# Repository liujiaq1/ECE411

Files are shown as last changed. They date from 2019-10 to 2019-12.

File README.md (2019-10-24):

# ECE411

## Team Members:
- Wenhao Cheng [cwenhao@pdx.edu](cwenhao@pdx.edu)
- Blaine R. Jemmett [brj@pdx.edu](brj@pdx.edu)
- Xuening Jia [xuening@pdx.edu](xuening@pdx.edu)
- Jiaqi Liu [liujiaq@pdx.edu](liujiaq@pdx.edu)

## Resources: 
- [ECE 411 Syllabus](http://web.cecs.pdx.edu/~faustm/ece411/syllabus.pdf)
- [ Practicum Project Information and Requirements](http://web.cecs.pdx.edu/~faustm/ece411/homework/PracticumProjectDescription.pdf)

## Meeting Minutes
- [10/17/2019](https://github.com/liujiaq1/ECE411-Team9/blob/master/Meetings/10-17-2019/README.md)

## Parts 
- [Parts List](https://github.com/liujiaq1/ECE411-Team9/blob/master/Parts%20List.xlsx)
- [Datasheets](https://github.com/liujiaq1/ECE411-Team9/blob/master/Datasheets/README.md)

## Homework Documents
- [HW2](https://github.com/liujiaq1/ECE411-Team9/blob/master/HWDocument/ECE411%20HW2.docx)
- [PDS](https://github.com/liujiaq1/ECE411-Team9/blob/master/HWDocument/PDS.pdf)

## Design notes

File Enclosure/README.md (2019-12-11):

# Enclosure

<center>
<table>
  <tr>
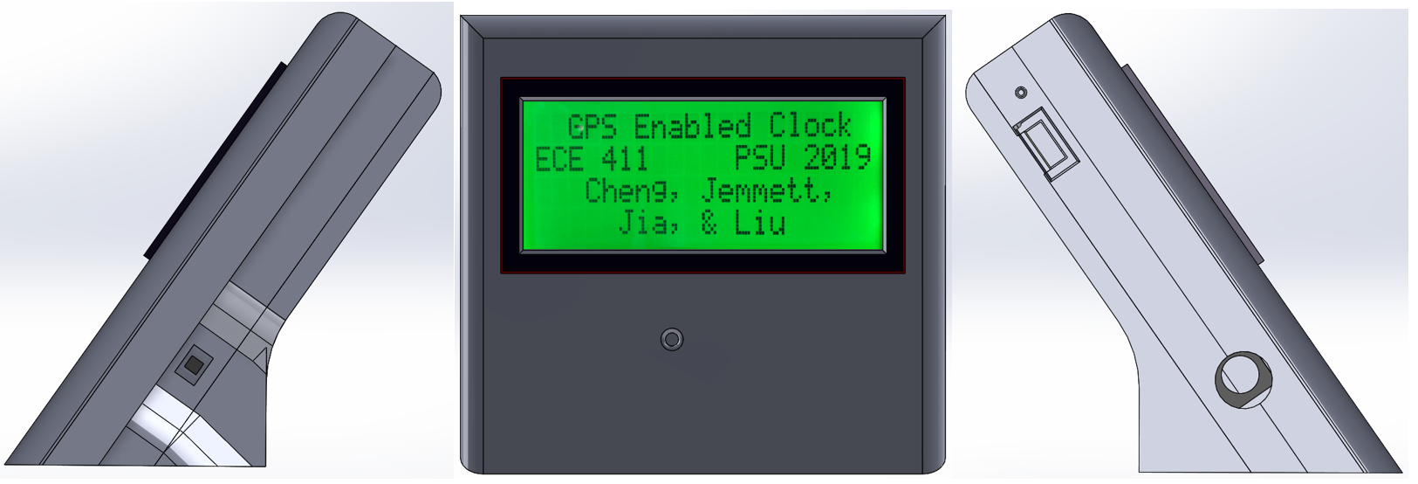
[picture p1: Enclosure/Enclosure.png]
Enclosure
    
  </tr>
  <tr>
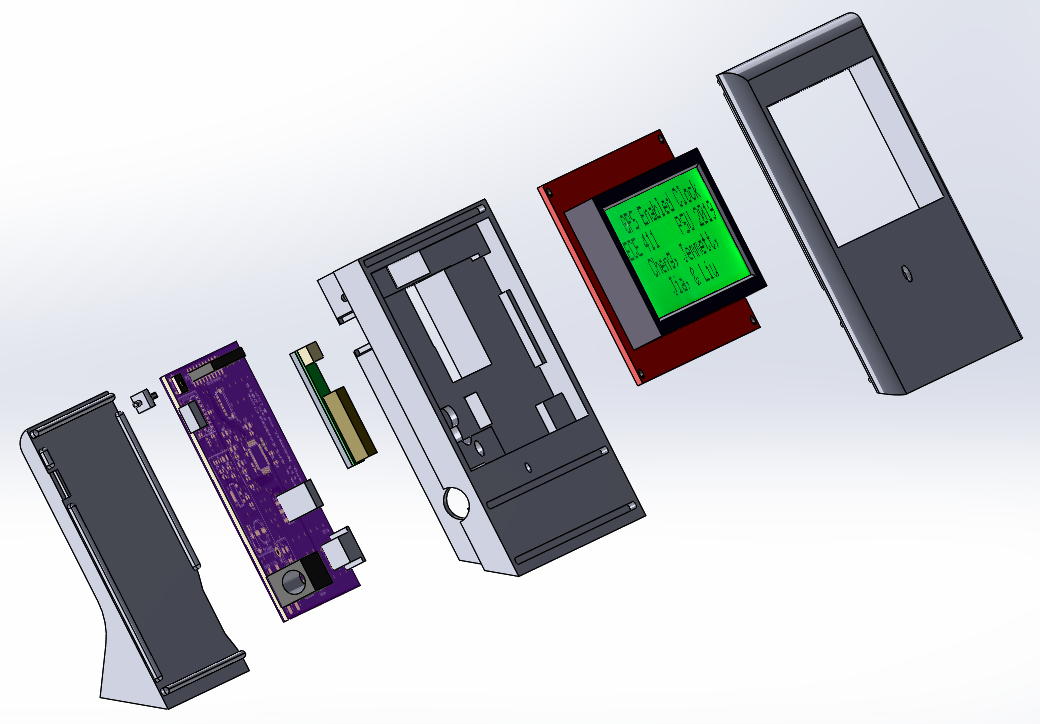
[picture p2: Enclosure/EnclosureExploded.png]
Exploder Enclosure
    
  </tr>
</table>
</center>

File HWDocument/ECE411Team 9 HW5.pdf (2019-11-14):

## ECE 411 Industry Design Processes: Assignment #5

## Due on Thursday, November 14, 2019

## Team: T09

## W. Cheng, Blaine R. Jemmett, X. Jia, J. Liu

Draw a high-level block diagram of your practicum project showing all inputs and

outputs.

# GPS enabled clock: Level 0

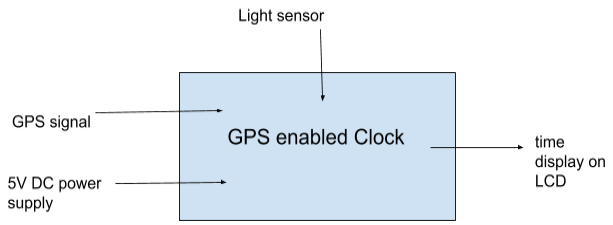
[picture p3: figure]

Module | GPS enabled clock
Inputs | Light sensor, GPS receiver, DC power supply
Outputs | 20x4 RGB LCD
Functionality | Uses a GPS receiver that receives location information and sends it to the Adruino. Then, Adruino will set the time automatically on LCD.

# GPS enabled clock: Level 1

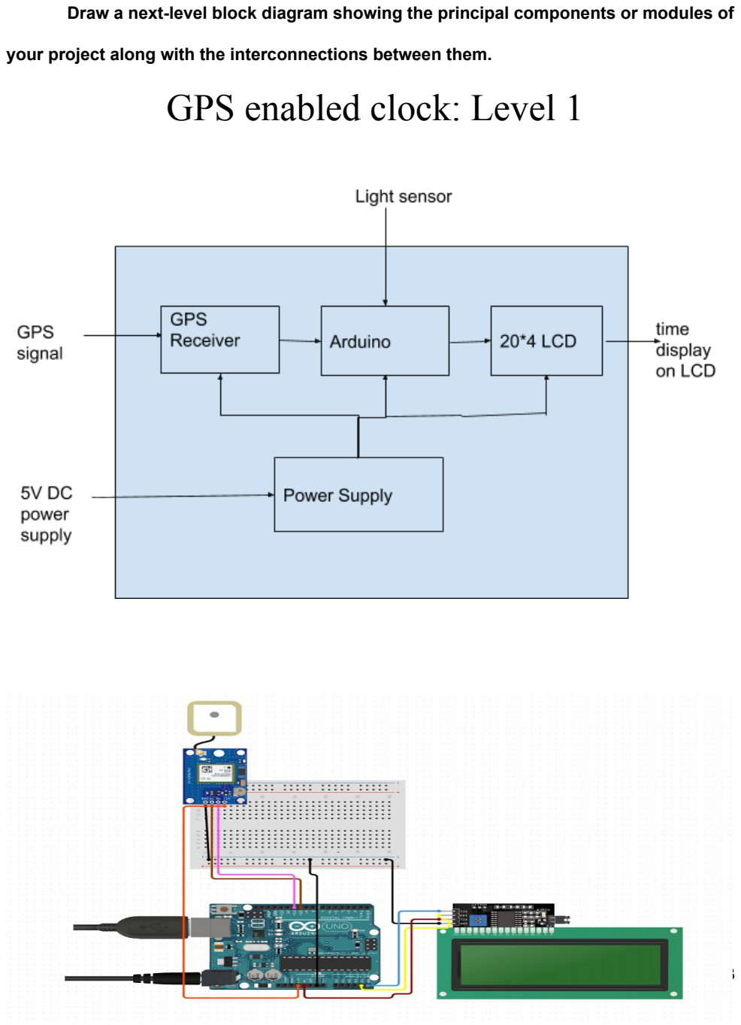
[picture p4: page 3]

Draw a next-level block diagram showing the principal components or modules of

your project along with the interconnections between them.

Draw a next-level block diagram showing the principal components or modules of your

project along with the interconnections between them.

# GPS Receiver: Level 1

For each component or module in the next-level block diagram, create a top-level block

diagram of that component or module that describes its functionality, inputs, and

outputs.

Module | GPS Receiver
Inputs | GPS signal, 3.3V from Power Supply
Outputs | GPS data sent to Arduino
Functionality | GPS Receiver can get the user position, velocity and precise time, by processing the signal broadcast by the GPS satellites.

# Arduino: Level 1

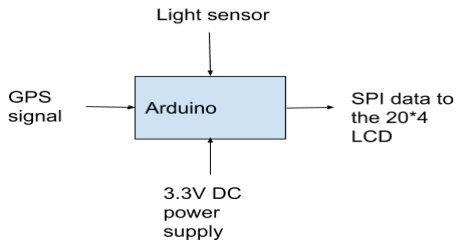
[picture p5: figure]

Module | Arduino
Inputs | GPS data from GPS receiver, 3.3V from Power Supply, Light sensor
Outputs | SPI data to the 20*4 LCD
Functionality | Arduino can receive and analyze GPS information. Finally, the result is shown on LCD. Brightness to LCD should be controlled by the amount of light received at the light sensor.

# 20*4 LCD: Level 1

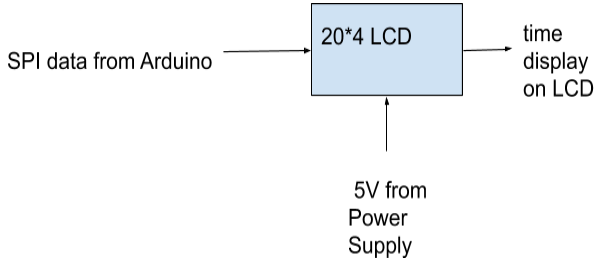
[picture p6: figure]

Module | 20*4 LCD
Inputs | SPI data from Arduino, 5V from Power Supply
Outputs | Visual information on the display screen
Functionality | Displaying text (time, date, etc) sent by Arduino.

# Power Supply: Level 1

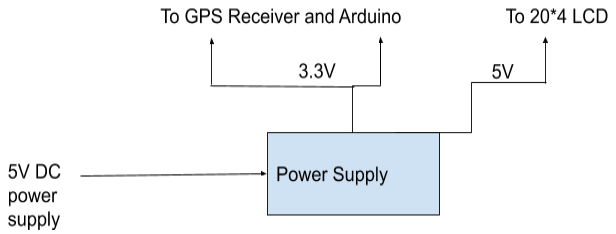
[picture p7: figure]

Module | Power Supply
Inputs | 5V DC power supply
Outputs | 5V/3.3V DC power supply
Functionality | It provides the power the whole device using a 120V AC power supply to 5V DC power supply or USB.

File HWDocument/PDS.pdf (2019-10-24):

## ECE 411 Industry Design Processes: Assignment #2

## Due on Thursday, October 24, 2019

## Team: T09

## W. Cheng, Blaine R. Jemmett, X. Jia, J. Liu

## Project Design Specification (PDS)

## for

## GPS enabled clock

## Version 1.0

## October 24, 2019

## Table of Contents

Introduction

Purpose of the Product Design Specification Document

Project Overview

System Architecture

Requirements

Functional Requirements

Performance Requirements

Economic and Marketing Requirements

Power Requirements

Health and Safety

Maintainability

Operational Environment

Usability

REFERENCES

Introduction:

A GPS clock having high precision positioning timing prevents people from having to

manually adjust to local time when they go to different places. The GPS clock is not affected by

various electromagnetic interferences, and the time is accurate and is not limited by geography.

Although such products are already on the market, the expensive price cannot meet the

budgetary requirements of ordinary families. The purpose of the project is to create this clock

having more accurate time at a lower price so that more people can afford it.

Purpose of the Product Design Specification Document:

The purpose of the product design specification is to confirm that the subsequent design and

development of the product can meet the needs of the users. The project must meet all the

requirements that “Must” be completed in the specification document. “Should” and “May” are

additional but not necessary.

Project Overview

This project solves the problem of the prohibitive cost of traditional GPS clocks. The

GPS clock has a GPS receiver - GP-735 (56 channels) that receives GPS satellite signals. The

receiver is very small and convenient, and it can turn on/off the power through the GPIO control

pin. This can achieve the purpose of saving power loss when the GPS function is not used.

Therefore, the project achieves a small size, low cost, energy-saving, etc.

System Architecture

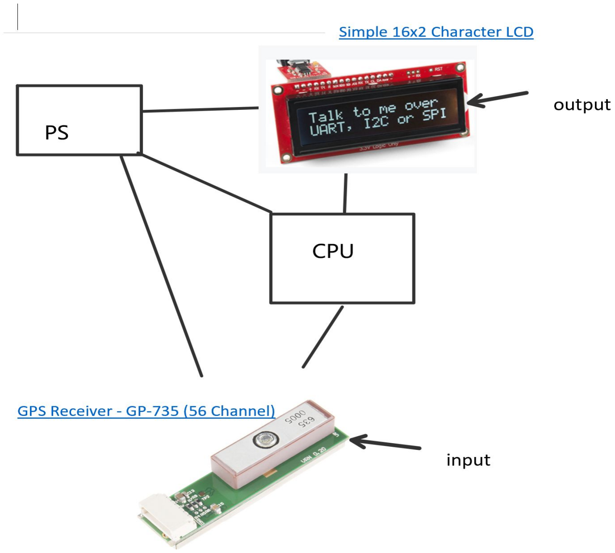
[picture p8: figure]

User Characteristic

The following sections list the main user types to better describe the expected target

market.

- Students

The people who live and study in different places or different time zone is more likely to

buy this product. They can know the time even they go back home or go to school without

setting a clock. It is very convenient for these people to know the time.

- Commuters and Travelers

People who like to fly or bus are always very time-conscious, and they are always

worried about missing flights or trains. The GPS clock accurately provides them with the correct

time for appropriate arrival times.

Assumptions

- Users are familiar with the ECE 411 practicum design guidelines.
- The system works in different regions.
- The system is at the temperature at which it can work.

Constraints

- Must be completed within a limited time (8 to 10 weeks).
- Use a two or more layer PCB.
- Have one or more sensors (inputs).
- Have one or more actuators (outputs).
- Have one or more processing modules which control actuators based on sensors.
- Use 25% or more surface mount components that can be hand or reflow soldered.

Requirements:

### 1. Functional Requirements:

Req# | Requirement | Priority | Station
1.1 | Have one or more inputs or sensors | Must | GPS module
1.2 | receive GPS signal | Must | GPS module
1.3 | Communicate with an alphanumeric display by a simple SPI interface | Must | LCD/GPS module
1.4 | Hot and cold resistant | Should | LCD/GPS module
1.5 | Detect ambient light levels and adjust LCD accordingly | Should | LCD Module
1.6 | Alarm setting | Should | CPU
1.7 | Automatically adjust for DST | Should | CPU
Table 1: Functional Requirements

### 2. Performance Requirements:

Req# | Requirement | Priority | Station
2.1 | GPS module update frequency range is 5Hz -10Hz | Must | GPS module
2.2 | These tiny GPS units can use a lot of power around 30mA at 3.3V On average | Must | GPS module

Table 2: Performance Requirements

### 3. Economic and Marketing Requirements:

Req# | Requirement | Priority | Station
3.1 | Should not use non-standard components | Should | GPS module
3.2 | Buying 25 or more will save $3.76/each | Should | LCD/GPS module
3.3 | The whole product can be sold as $60 | Should | LCD/GPS module

Table 3: Economic and Marketing Requirements

### 4. Power Requirements:

Req# | Requirement | Priority | Station
4.1 | A 5V (https://www.sparkfun.com/products/12889) Wall Adapter Power Supply provides all the power for the displays and to power the Arduino | Must | LCD/GPS module
4.2 | Peak current shall not exceed 2000mA | Must | LCD/GPS module
4.3 | The GPS module to be powered down when not in use | Must | GPS module

Table 4: Power Requirements

### 5. Health and Safety:

Req# | Requirement | Priority | Station
5.1 | Make sure the product will not injure people. | Must | LCD/GPS module

Table 5: Health and Safety

### 6. Maintainability:

Req# | Requirement | Priority
6.1 | Record the progress of the project every week | Must
6.2 | Progress reports may be submitted by email | May
6.3 | Record experimental data and results via Github | May

Table 6: Maintainability

### 7. Operational Environment:

Req# | Requirement | Priority | Station
7.1 | Can work in hot and cold environments | Should | LCD/GPS module

Table 7: Operational Environment

### 8. Usability:

Req# | Requirement | Priority | Station
8.1 | Users are able to use the system without training | Must | LCD/GPS module

Table 8: Usability

### 9. Manufacturability:

Req# | Requirement | Priority | Station
9.1 | Must be possible to assemble by hand | Must | LCD/GPS module
9.2 | Use 25% or more surface mount components that can be hand or reflow soldered | Must | LCD/GPS module

Table 9: Manufacturability

REFERENCES

https://en.wikipedia.org/wiki/Product_design_specification

https://learn.sparkfun.com/tutorials/gps-basics

https://en.wikipedia.org/wiki/Global_Positioning_System

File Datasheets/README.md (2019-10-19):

# Datasheets

<table>
  <tr>
    <th>Part</th> <th>Datasheet</th>
  </tr>
    <td><a href="https://www.sparkfun.com/products/13448">ATMEGA328P-AU</a></td> <td><a href="https://github.com/liujiaq1/ECE411-Team9/blob/master/Datasheets/ATMega328.pdf">PDF Datasheet</a></td>
  <tr>
    <td><a href="https://www.sparkfun.com/products/14074">SparkFun 20x4 SerLCD - Black on RGB 3.3V</a></td> <td><a href="https://github.com/sparkfun/OpenLCD">Datasheet Link</a></td>
  </tr>
  <tr>
    <td><a href="https://www.sparkfun.com/products/13670">GPS Receiver - GP-735 (56 Channel)</a></td> <td><a href="https://github.com/liujiaq1/ECE411-Team9/blob/master/Datasheets/GP-735T-150203.pdf">PDF Datasheet</a></td>
  </tr>
  <tr>
    <td><a href="https://www.sparkfun.com/products/12566">ALS-PT19 Light Sensor</a></td> <td><a href="https://github.com/liujiaq1/ECE411-Team9/blob/master/Datasheets/ALS-PT19-315C-L177-TR_datasheet.pdf">PDF Datasheet</a></td>
  </tr>
  <tr>
    <td></td> <td></td>
  </tr>   
</table>

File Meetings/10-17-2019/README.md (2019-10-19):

# Attendees
<pre>
Blaine
Jackie
Wenhao
Xuening
</pre>

# Homework
<pre>
Sorted out the differences between HW2 for Lecture vs Practicum
</pre>

# Project
<pre>
Discussed each persons background, skills, and classes
Agreed on GPS clock
Talked about and agreed on using GPS Receiver - GP-735 (56 Channel)
</pre

<table>
  <tr>
    <th><a href="https://www.sparkfun.com/products/13670" title="GPS Receiver - GP-735 (56 Channel)">GPS Receiver - GP-735 (56 Channel)</a></th>
  </tr>
</table>

<pre>
Agreed on highlevel block diagram 
</pre>

<center>
<table>
  <tr>
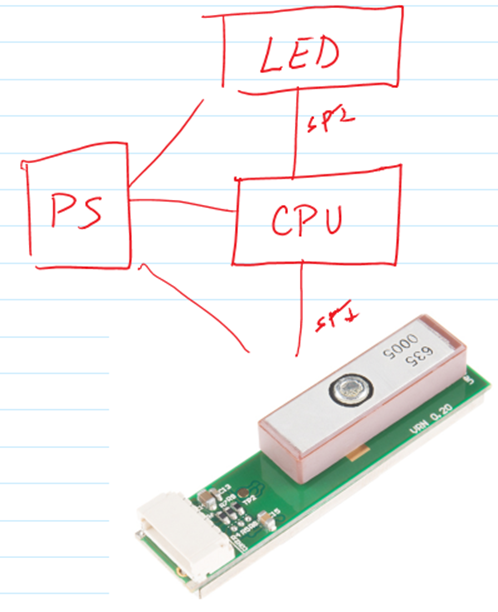
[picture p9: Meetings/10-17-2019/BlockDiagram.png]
Block Diagram
    
  </tr>
</table>
</center>

<pre>
Discussed pros and cons about simple character LCDs versus graphic LCDs. 
Compared simple 16x2 Character LCD to 128x32 graphics LCD. 
Decided to send email to ask for advice on required complexity of the project. 
</pre>

<table>
  <tr>
    <th><a href="https://www.sparkfun.com/products/14073/" title="Simple 16x2 Character LCD">Simple 16x2 Character LCD</a></th> 
    <th><a href="https://www.digikey.com/product-detail/en/newhaven-display-intl/NHD-C12832A1Z-NSW-BBW-3V3/NHD-C12832A1Z-NSW-BBW-3V3-ND/2059235/" title="128x32 Graphics LCD">128x32 Graphics LCD</a></th>
  </tr>
  <tr>
    <td>
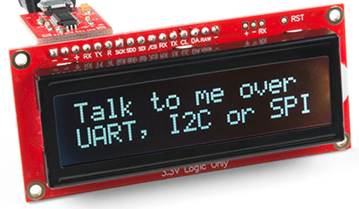
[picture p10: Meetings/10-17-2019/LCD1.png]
Simple 16x2 Character LCD
      
    </td>
    <td>
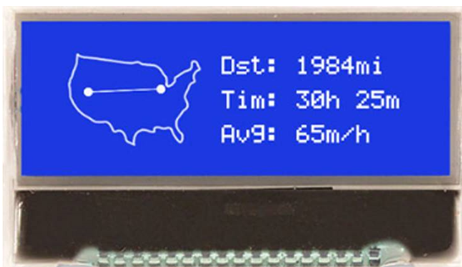
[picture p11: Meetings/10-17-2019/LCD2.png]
128x32 Graphics LCD
      
    </td>
  </tr>
</table>

<pre>
Decided to use Google Docs for collaboration on PSD
</pre>

# ARs

### Blaine: email Eric and Andrew about which LCD type would be accepable for the project 
- [x] Completed: 10\17\2019
>> [Andrew's Response. email 10/17/2019] I'm not sure what you mean by "acceptable". Both LCDs are perfectly acceptable as "actuators" in the practicum project.
**The first LCD is simple to use character-based LCD, straight forward to use, and would make an excellent choice for a simple practicum project.**
The second LCD is a widely used graphical LCD that requires a C graphics library and, in my opinion, a 32 bit microcontroller with plenty of flash and RAM. If you'd like to go down that route, that's perfectly acceptable, although of course *I wouldn't suggest you do that.*
Hope that helps.
>>
> Will use [Simple 16x2 Character LCD](https://www.sparkfun.com/products/14073/)
>

### Blaine:  Post initial parts list
- [x] Completed: 10\18\2019
>

### Jackie:  Markup practicum HW2, Post to Git, and email Andrew and Eric as soon as possible
- [ ] Completed: xx\xx\xxxx
> Insert info or delete
>

### Jackie:  Create PDS document in Google Docs
- [ ] Completed: xx\xx\xxxx
> Insert info or delete
>

### All:  Work on PDS in Google Docs
- [ ] Completed: xx\xx\xxxx
> Insert info or delete
>

### Jackie:  Post compledted PDS to GIT prior to due date
- [ ] Completed: xx\xx\xxxx
> Insert info or delete
>

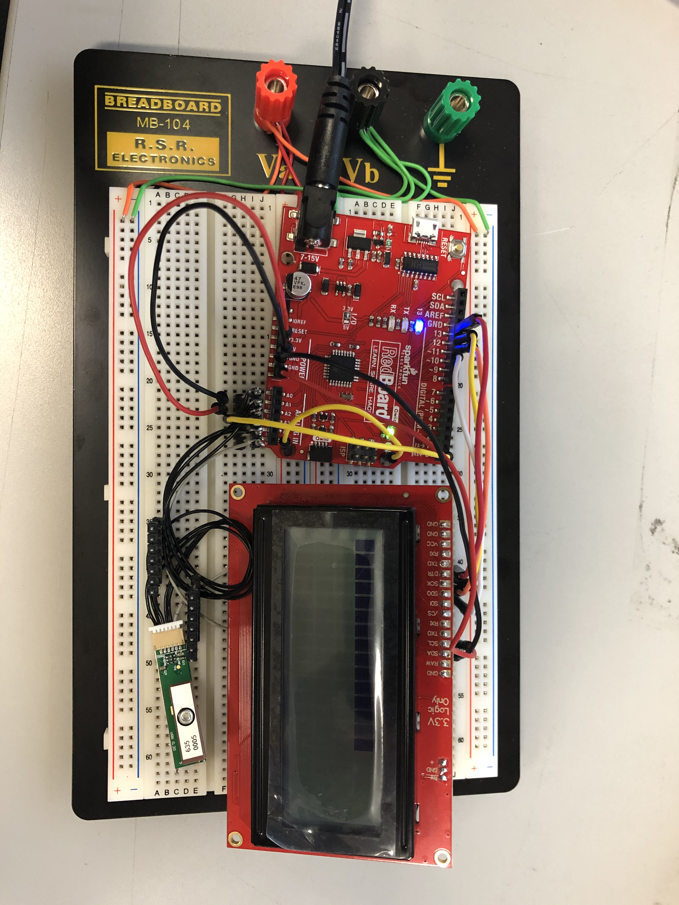
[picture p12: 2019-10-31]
HWDocument/HW4 Picture.jpg

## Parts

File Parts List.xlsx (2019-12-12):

Status | Part |  | Link | Quantity |  | Price |  |  | Vmin | Vmax | Through Hole |  | SMD |  |  | Bought
 |  | Source |  | Per Board | Total | Per Part | Per Board | Total |  |  |  | QTY |  | QTY |  | Cheng | Jemmett | Jia | Liu
 | PCB | Osh Park |  | 1 | 4 | $8.51 | $8.51 | $34.04
In House | GPS Module | Sparkfun | https://www.sparkfun.com/products/13670 | 1 | 4 | $45.95 | $45.95 | $183.80 | 3.1 | 5.5 |  |  |  |  |  |  | 1
In House | Solder Stencil kit | Osh Stencil |  |  |  |  | $15.53 | $62.11
In House | GPS PCB Connector | Sparkfun | https://www.sparkfun.com/products/10210 | 1 | 4 | $0.95 | $0.95 | $3.80 |  |  |  |  |  |  |  |  | 2
In House | 20x4 RGB LCD | Sparkfun | https://www.sparkfun.com/products/14074 | 1 | 4 | $24.95 | $24.95 | $99.80 | 3.3 | 9 |  |  | X | 1 |  |  | 2
In House | Light sensor | Sparkfun | https://www.sparkfun.com/products/12566 | 1 | 4 | $0.95 | $0.95 | $3.80 | -0.5 | 6 |  |  | X | 1 |  |  | 3
In House | ATMEGA328P-AU | Sparkfun | https://www.sparkfun.com/products/13448 | 1 | 4 | $4.25 | $4.25 | $17.00 | 1.8 | 5 |  |  | X | 1 |  |  | 2
In House | Cap: 0.1UF-0603-25V-(+80/-20%) | Digi-Key | https://www.digikey.com/product-detail/en/kemet/C0603C104Z3VACTU/399-1100-1-ND/411375 | 10 | 40 | $0.10 | $1.00 | $4.00 |  |  |  |  | X | 10 |  |  | 20
In House | Cap: 1.0UF-16V-10%(0603) | Digi-Key | https://www.digikey.com/product-detail/en/knowles-novacap/0603BB105K160YT/1763-1175-1-ND/7304294 | 1 | 4 | $1.61 | $1.61 | $6.44 |  |  |  |  | X | 1 |  |  | 10
In House | Res: 10KOHM-0603-1/10W-1% | Digi-Key | https://www.digikey.com/product-detail/en/yageo/RC0603FR-0710KL/311-10.0KHRCT-ND/729827 | 3 | 12 | $0.10 | $0.30 | $1.20 |  |  |  |  | X | 3 |  |  | 10
In House | Cap: 10NF/10000PF-50V-10%(0603) | Digi-Key | https://www.digikey.com/products/en/capacitors/ceramic-capacitors/60?k=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 | 1 | 4 | $0.62 | $0.62 | $2.48 |  |  |  |  | X | 1 |  |  | 10
In House | Cap: 10UF-POLAR-EIA3216-16V-10%(TANT) | Digi-Key | https://www.digikey.com/product-detail/en/avx-corporation/F931C106KAA/478-8235-1-ND/4005599 | 3 | 12 | $0.46 | $1.38 | $5.52 |  |  |  |  | X | 3 |  |  | 10
In House | 1571984-1 | Digi-Key | https://www.digikey.com/products/en?keywords=TE%201571984-1 | 1 | 4 | $6.19 | $6.19 | $24.76 |  |  | X | 1 |  |  |  |  | 1
In House | RESONATOR-16MHZSMD_3.2X1.3 | Digi-Key | https://www.digikey.com/product-detail/en/murata-electronics/CSTNE16M0V53C000R0/490-17949-1-ND/8747757 | 1 | 4 | $0.36 | $0.36 | $1.44 |  |  |  |  | X | 1 |  |  | 5
In House | DIODE-SCHOTTKY-SS14 | Digi-Key | https://www.digikey.com/product-detail/en/on-semiconductor/SS14/SS14CT-ND/965729 | 1 | 4 | $0.39 | $0.39 | $1.56 |  |  |  |  | X | 1 |  |  | 3
In House | MOSFET-PCH-ZXMP6A13F | Digi-Key | https://www.digikey.com/product-detail/en/diodes-incorporated/ZXMP6A13FTA/ZXMP6A13FCT-ND/560665 | 1 | 4 | $0.55 | $0.55 | $2.20 |  |  |  |  | X | 1 |  |  | 3
In House | Res: 1MOHM-0603-1/4W-5% | Digi-Key | https://www.digikey.com/product-detail/en/vishay-dale/CRCW06031M00JNEAHP/541-1.0MSACT-ND/2222829 | 1 | 4 | $0.16 | $0.16 | $0.64 |  |  |  |  | X | 1 |  |  | 10
In House | Res: 1KOHM-0603-1/10W-1% | Digi-Key | https://www.digikey.com/product-detail/en/yageo/RC0603FR-071KL/311-1.00KHRCT-ND/729790 | 1 | 4 | $0.10 | $0.10 | $0.40 |  |  |  |  | X | 1 |  |  | 10
In House | Res: 240OHM-0603-1/10W-1% | Digi-Key | https://www.digikey.com/product-detail/en/stackpole-electronics-inc/RMCF0603FT240R/RMCF0603FT240RCT-ND/4376679 | 1 | 4 | $0.10 | $0.10 | $0.40 |  |  |  |  | X | 1 |  |  | 10
In House | 4.7KOHM-0603-1/10W-1% | Digi-Key | https://www.digikey.com/product-detail/en/yageo/RC0603FR-074K7L/311-4.70KHRCT-ND/730159 | 3 | 12 | $0.10 | $0.30 | $1.20 |  |  |  |  | X | 3 |  |  | 10
In House | Cap: 47UF-POLAR-PANASONIC_D-35V-20% | Digi-Key | https://www.digikey.com/product-detail/en/panasonic-electronic-components/EEE-1VA470WP/PCE3961CT-ND/766337 | 1 | 4 | $0.41 | $0.41 | $1.64 |  |  |  |  | X | 1 |  |  | 2
In House | Res: 715OHM-0603-1/10W-1% | Digi-Key | https://www.digikey.com/product-detail/en/yageo/RC0603FR-07715RL/311-715HRCT-ND/730318 | 1 | 4 | $0.10 | $0.10 | $0.40 |  |  |  |  | X | 1 |  |  | 10
In House | USB_MICRO-B_HALF_PTH_MILL | Digi-Key | https://www.digikey.com/product-detail/en/amphenol-icc-fci/10103594-0001LF/609-4050-1-ND/2350357 | 1 | 4 | $0.79 | $0.79 | $3.16 |  |  |  |  | X | 1 |  |  | 1
In House | V_REG_AP2112K-3.3V | Digi-Key | https://www.digikey.com/product-detail/en/diodes-incorporated/AP2112K-3.3TRG1/AP2112K-3.3TRG1DICT-ND/4505257 | 1 | 4 | $0.47 | $0.47 | $1.88 |  |  |  |  | X | 1 |  |  | 3
In House | LED-BLUE_HIDDENSILK | Digi-Key | https://www.digikey.com/product-detail/en/lite-on-inc/LTST-C150TBKT/160-1643-1-ND/573584 | 1 | 4 | $0.54 | $0.54 | $2.16 |  |  |  |  | X | 1 |  |  | 2
In House | LED-GREEN_HIDDENSILK | Digi-Key | https://www.digikey.com/product-detail/en/lite-on-inc/LTST-C150KGKT/160-1404-1-ND/386759 | 1 | 4 | $0.45 | $0.45 | $1.80 |  |  |  |  | X | 1 |  |  | 2
In House | LED-GREEN_HIDDENSILK | Digi-Key | https://www.digikey.com/product-detail/en/lite-on-inc/LTST-C150KGKT/160-1404-1-ND/386759 | 1 | 4 | $0.37 | $0.37 | $1.48 |  |  |  |  | X | 1 |  |  | 2
In House | AVR_SPI_PROG_3X2SMD | Digi-Key | https://www.digikey.com/product-detail/en/molex/0877590614/WM18713-ND/769538 | 1 | 4 | $0.37 | $0.37 | $1.48 |  |  |  |  | X | 1 |  |  | 1
In House | V_REG_LM1117ALT1 | Digi-Key | https://www.digikey.com/product-detail/en/texas-instruments/LM1117MPX-5.0-NOPB/LM1117MPX-5.0-NOPBCT-ND/660149 | 1 | 4 | $0.99 | $0.99 | $3.96 |  |  |  |  | X | 1 |  |  | 2
In House | PPTC_6V500MA | Digi-Key | https://www.digikey.com/product-detail/en/littelfuse-inc/0402L020SLKR/F5757CT-ND/3593804 | 1 | 4 | $1.10 | $1.10 | $4.40 |  |  |  |  | X | 1 |  |  | 2
In House | TP-063 | Digi-Key | https://www.digikey.com/product-detail/en/keystone-electronics/5011/36-5011-ND/255333 | 1 | 4 | $0.04 | $0.04 | $0.14 |  |  | X | 1 |  |  |  |  | 1
In House | LED-YELLOW_HIDDENSILK | Digi-Key | https://www.digikey.com/product-detail/en/lite-on-inc/LTST-C150KSKT/160-1406-1-ND/386762 | 1 | 4 | $1.50 | $1.50 | $6.00 |  |  |  |  | X | 1 |  |  | 2
In House | POWER_JACKSUPER_BOMB_DIGITY | Sparkfun | https://www.sparkfun.com/products/12748 | 1 | 4 | $2.87 | $2.87 | $11.48 |  |  |  |  | X | 1 |  |  | 1
In House | MOMENTARY-SWITCH-SPST-2-SMD-5.2MM-TALL | Sparkfun | https://www.sparkfun.com/products/8720 | 1 | 4 | $0.95 | $0.95 | $3.80 |  |  |  |  | X | 1 |  |  | 1
In House | USB to Serial: CH340C | UTSource | https://www.utsource.net/itm/p/8831730.html?digipart=1 | 1 | 4 | $0.35 | $0.35 | $1.40 |  |  |  |  | X | 1 |  |  | 4
In House | 1x10 SMD Header Female |  | Sourcing from RedBoard | 1 | 4 | $0.37 | $0.37 | $1.48 |  |  |  |  | X | 1
 |  |  |  | 50 | 200 | $108.06 | $125.81 | $503.25 | -0.50 | 9.00 |  | 2 |  | 45 | Count
 |  |  |  |  |  |  |  |  |  |  |  | 4.26% |  | 95.74% | Percentage

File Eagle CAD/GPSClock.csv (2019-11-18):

Qty | Value | Device | Package | Parts | Description | MANUFACTURER_PART_NUMBER | PROD_ID | SF_ID | VALUE | VENDOR
10 | 0.1uF | 0.1UF-0603-25V-(+80/-20%) | 0603 | C1, C2, C4, C8, C9, C10, C11, C12, C13, C18 | 0.1µF ceramic capacitors |  | CAP-00810 |  | 0.1uF
1 | 1.0uF | 1.0UF-16V-10%(0603) | 0603-CAP | C16 | CAP-00868 |  | CAP-00868 |  | 1.0uF
3 | 10k | 10KOHM-0603-1/10W-1% | 0603 | R2, R3, R4 | 10kΩ resistor |  | RES-00824 |  | 10k
1 | 10nF | 10NF/10000PF-50V-10%(0603) | 0603-CAP | C17 | CAP-00867 |  | CAP-00867 |  | 10nF
3 | 10uF | 10UF-POLAR-EIA3216-16V-10%(TANT) | EIA3216 | C3, C6, C15 | 10.0µF polarized capacitors |  | CAP-00811 |  | 10uF
1 | 1571984-1 | 1571984-1 | SWITCH_1571984-1 | U5 |  | 15719841 |  |  |  | TE Connectivity
1 | 16MHz | RESONATOR-16MHZSMD_3.2X1.3 | RESONATOR-SMD-3.2X1.3 | Y1 | 16MHz Resonator |  | XTAL-08900 |  | 16MHz
1 | 1A/40V/500mV | DIODE-SCHOTTKY-SS14 | SMA-DIODE | D1 | Schottky diode |  | DIO-08053 |  | 1A/40V/500mV
1 | 1A/60V/500mΩ | MOSFET-PCH-ZXMP6A13F | SOT23-3 | Q1 | P-channel MOSFETs |  | TRANS-08285 |  | 1A/60V/500mΩ
1 | 1M | 1MOHM-0603-1/4W-5% | 0603 | R7 | 1MΩ resistor |  | RES-07868 |  | 1M
1 | 1k | 1KOHM-0603-1/10W-1% | 0603 | R8 | 1kΩ resistor |  | RES-07856 |  | 1k
1 | 240 | 240OHM-0603-1/10W-1% | 0603 | R15 | 240Ω resistor |  | RES-07849 |  | 240
3 | 4.7k | 4.7KOHM-0603-1/10W-1% | 0603 | R1, R12, R16 | 4.7kΩ resistor |  | RES-07857 |  | 4.7k
1 | 47uF | 47UF-POLAR-PANASONIC_D-35V-20% | PANASONIC_D | C5 | 47µF polarized capacitors |  | CAP-08478 |  | 47uF
1 | 715 | 715OHM-0603-1/10W-1% | 0603 | R14 | 715Ω resistor |  | RES-07850 |  | 715
1 | AMP FCI 10103594-0001LF | USB_MICRO-B_HALF_PTH_MILL | USB-MICROB-PTH-MILL | J1 | USB Type Micro-B Connector |  | CONN-13711
1 | AP2112-3.3V | V_REG_AP2112K-3.3V | SOT23-5 | U3 | AP2112 - 600mA CMOS LDO Regulator w/ Enable |  | VREG-12457 |  | 3.3V
1 | ATMEGA328P_TQFP | ATMEGA328P_TQFP | TQFP32-08 | U4 |  |  | IC-09069 |  | ATMEGA328P_TQFP
1 | BM06B-SRSS-TB | JST_6_PIN_HORIZONTAL | JST-6-SMD-HORI-1.0MM | J4 | JST 6 pin horizontal connector |  | XXX-00000 |  | BM06B-SRSS-TB
1 | Blue | LED-BLUE_HIDDENSILK | LED-1206-HIDDENSILK | LED1 | Blue SMD LED |  | DIO-09911
1 | CH340C | CH340C | SO016 | U1 |  |  | IC-14038
1 | GREEN | LED-GREEN_HIDDENSILK | LED-1206-HIDDENSILK | LED5 | Green SMD LED |  | DIO-00862
1 | GREEN | LED-GREEN_HIDDENSILK | LED-1206-HIDDENSILK | LED2 | Green SMD LED |  | DIO-09910
1 | ISP | AVR_SPI_PROG_3X2SMD | 2X3_SMT_POSTS | J2 | AVR ISP 6 Pin |  | CONN-11415
4 | JUMPER-SMT_2_NC_TRACE_NO-SILK | JUMPER-SMT_2_NC_TRACE_NO-SILK | SMT-JUMPER_2_NC_TRACE_NO-SILK | JP2, JP3, JP4, JP5 | Normally closed trace jumper
1 | JUMPER-SMT_3_1-NC_TRACE_NO-SILK | JUMPER-SMT_3_1-NC_TRACE_NO-SILK | SMT-JUMPER_3_1-NC_TRACE_NO-SILK | JP6 | Normally closed trace jumper (1 of 2 connections)
1 | LIGHT_SENSORALS | LIGHT_SENSORALS | ALS-PT19 | U2 | Ambient Light Sensors - Phototransistors |  | IC-11836 | SEN-12566
1 | LM1117 | V_REG_LM1117ALT1 | SOT223-ALT1 | IC3 | Voltage Regulator LM1117 |  | VREG-08170
1 | M10SMD_COMBO | M10SMD_COMBO | 1X10_SMD_COMBINED | JP1 | Header 10 |  | CONN-11219
1 | POWER_JACKSUPER_BOMB_DIGITY | POWER_JACKSUPER_BOMB_DIGITY | POWER_JACK_SMD_OVERPASTE_SUPER_BOMB_DIGITY | J3 | Power Jack |  | CONN-08106
1 | PPTC_6V500MA | PPTC_6V500MA | 0805 | F1 | Resettable Fuse PPTC
1 | RESET | MOMENTARY-SWITCH-SPST-2-SMD-5.2MM-TALL | TACTILE_SWITCH_SMD_5.2MM | S1 | Momentary Switch (Pushbutton) - SPST - Two Circuits |  | SWCH-14139
1 | TP-063 | TP-063 | TP-063 | TP1 | TEST POINT
1 | Yellow | LED-YELLOW_HIDDENSILK | LED-1206-HIDDENSILK | D3 | Yellow SMD LED |  | DIO-09909

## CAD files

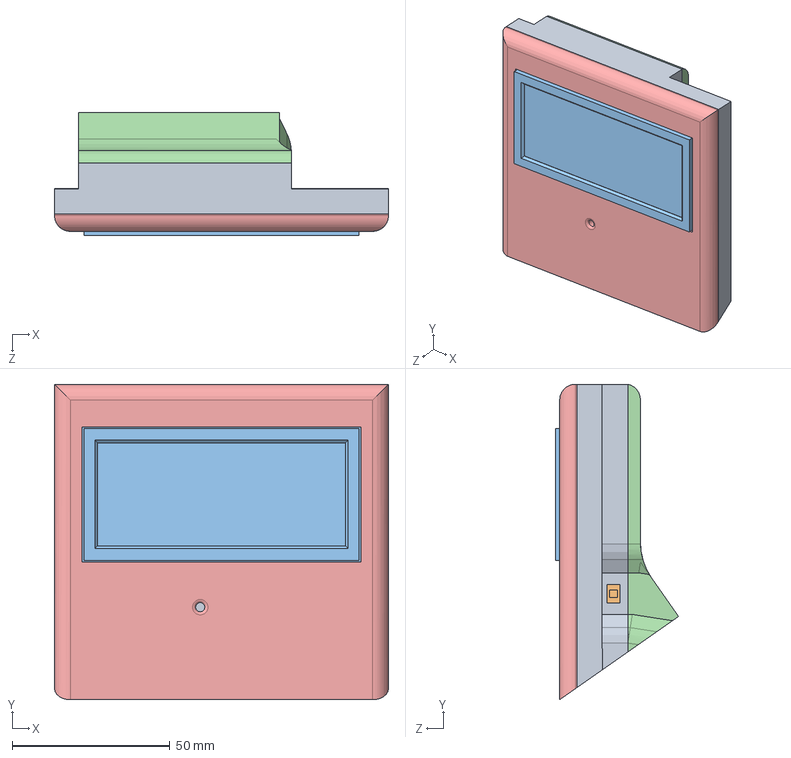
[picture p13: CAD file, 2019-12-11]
Enclosure/Assem2.SLDASM
105.9 x 100.0 x 39.0 mm
middle
PCB
LCD
back
Front
ResetButton
GPS

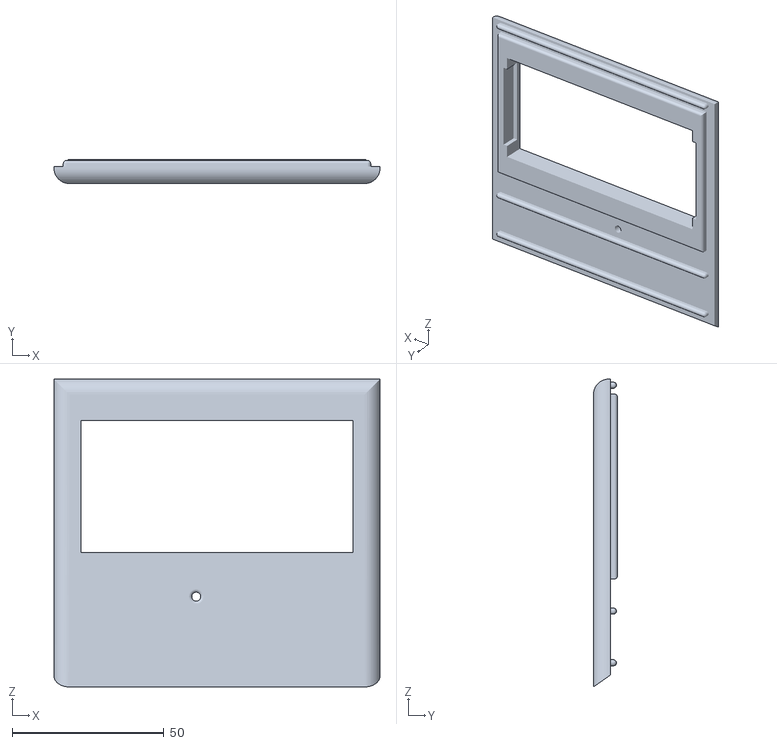
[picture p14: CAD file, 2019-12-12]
Enclosure/FrontScaled_1p014.STL
107.4 x 7.96 x 101.4

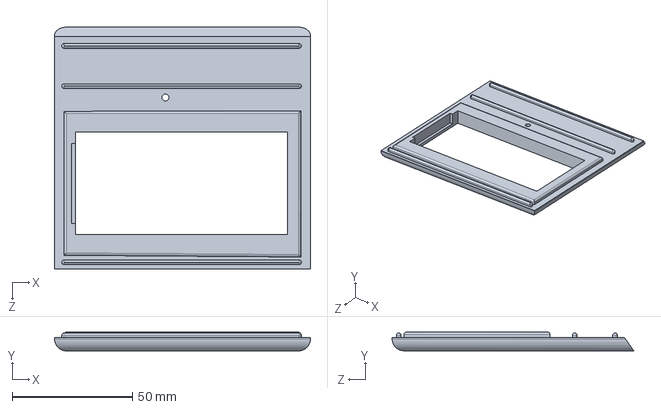
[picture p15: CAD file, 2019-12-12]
Front.SLDPRT
106.7 x 7.85 x 100.7 mm

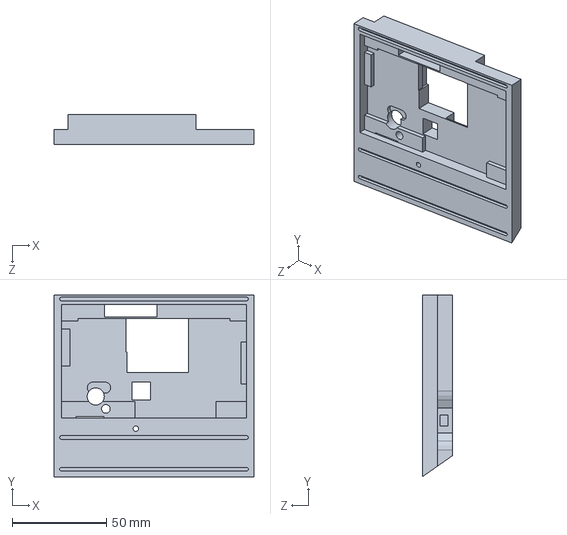
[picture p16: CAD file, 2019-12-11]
Enclosure/middle.SLDPRT
105.9 x 96.1 x 16.1 mm

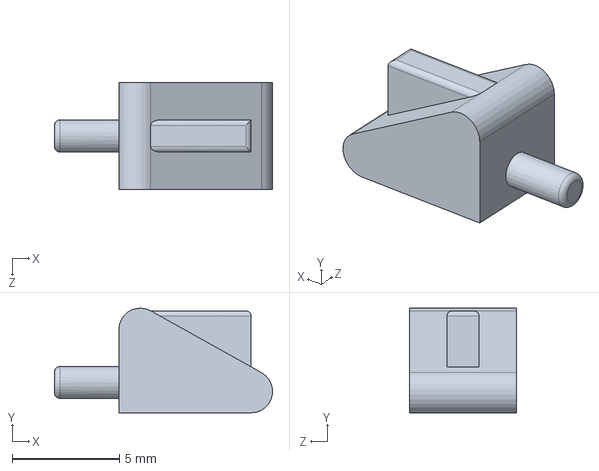
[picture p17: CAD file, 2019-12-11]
Enclosure/ResetButton.SLDPRT
10.2 x 4.88 x 5.00 mm

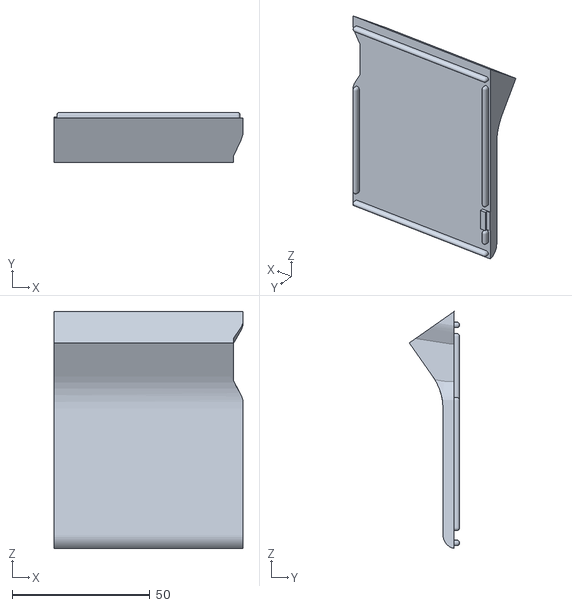
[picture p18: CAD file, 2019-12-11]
Enclosure/backScaled_1p014.STL
68.5 x 18.3 x 86.0

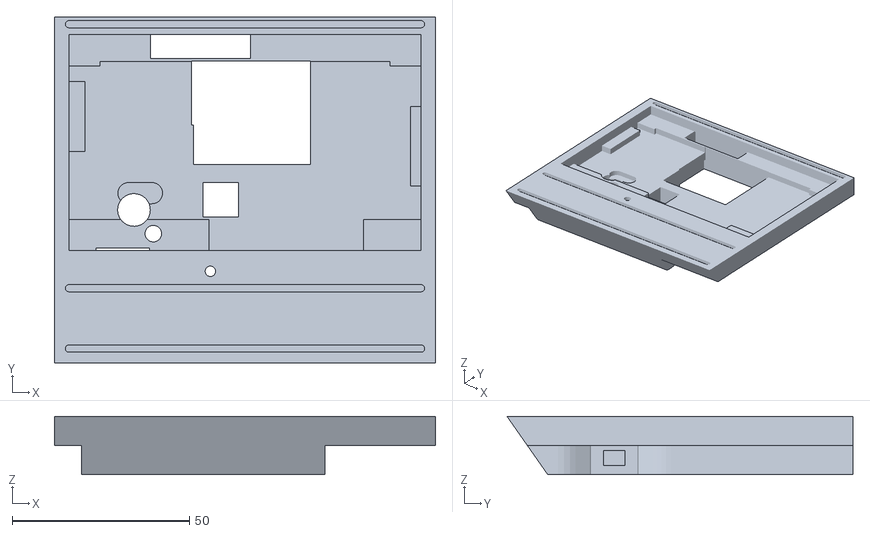
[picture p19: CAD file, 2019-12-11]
Enclosure/middleScaled_1p014.STL
107.4 x 97.5 x 16.4

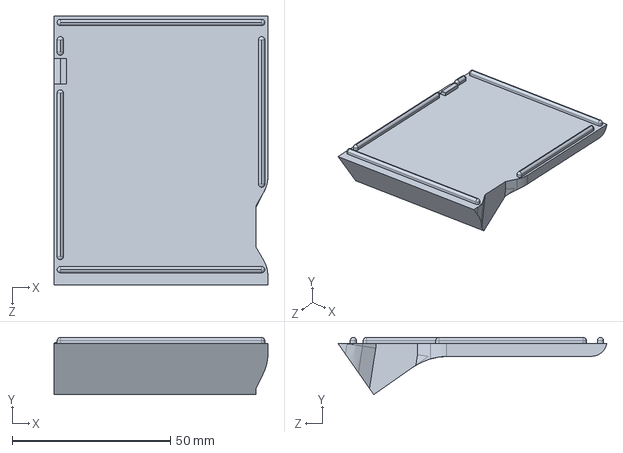
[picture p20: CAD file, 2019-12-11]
Enclosure/back.SLDPRT
67.6 x 18.1 x 84.8 mm

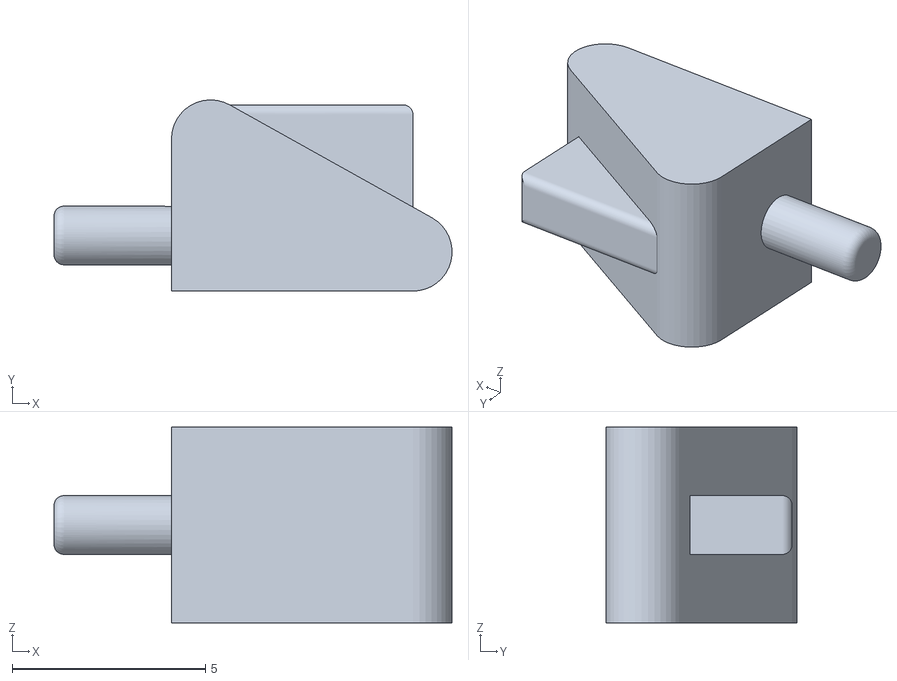
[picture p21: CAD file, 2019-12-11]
Enclosure/ResetButtonScaled_1p014.STL
10.3 x 4.95 x 5.07

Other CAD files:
Enclosure/Front.SLDPRT

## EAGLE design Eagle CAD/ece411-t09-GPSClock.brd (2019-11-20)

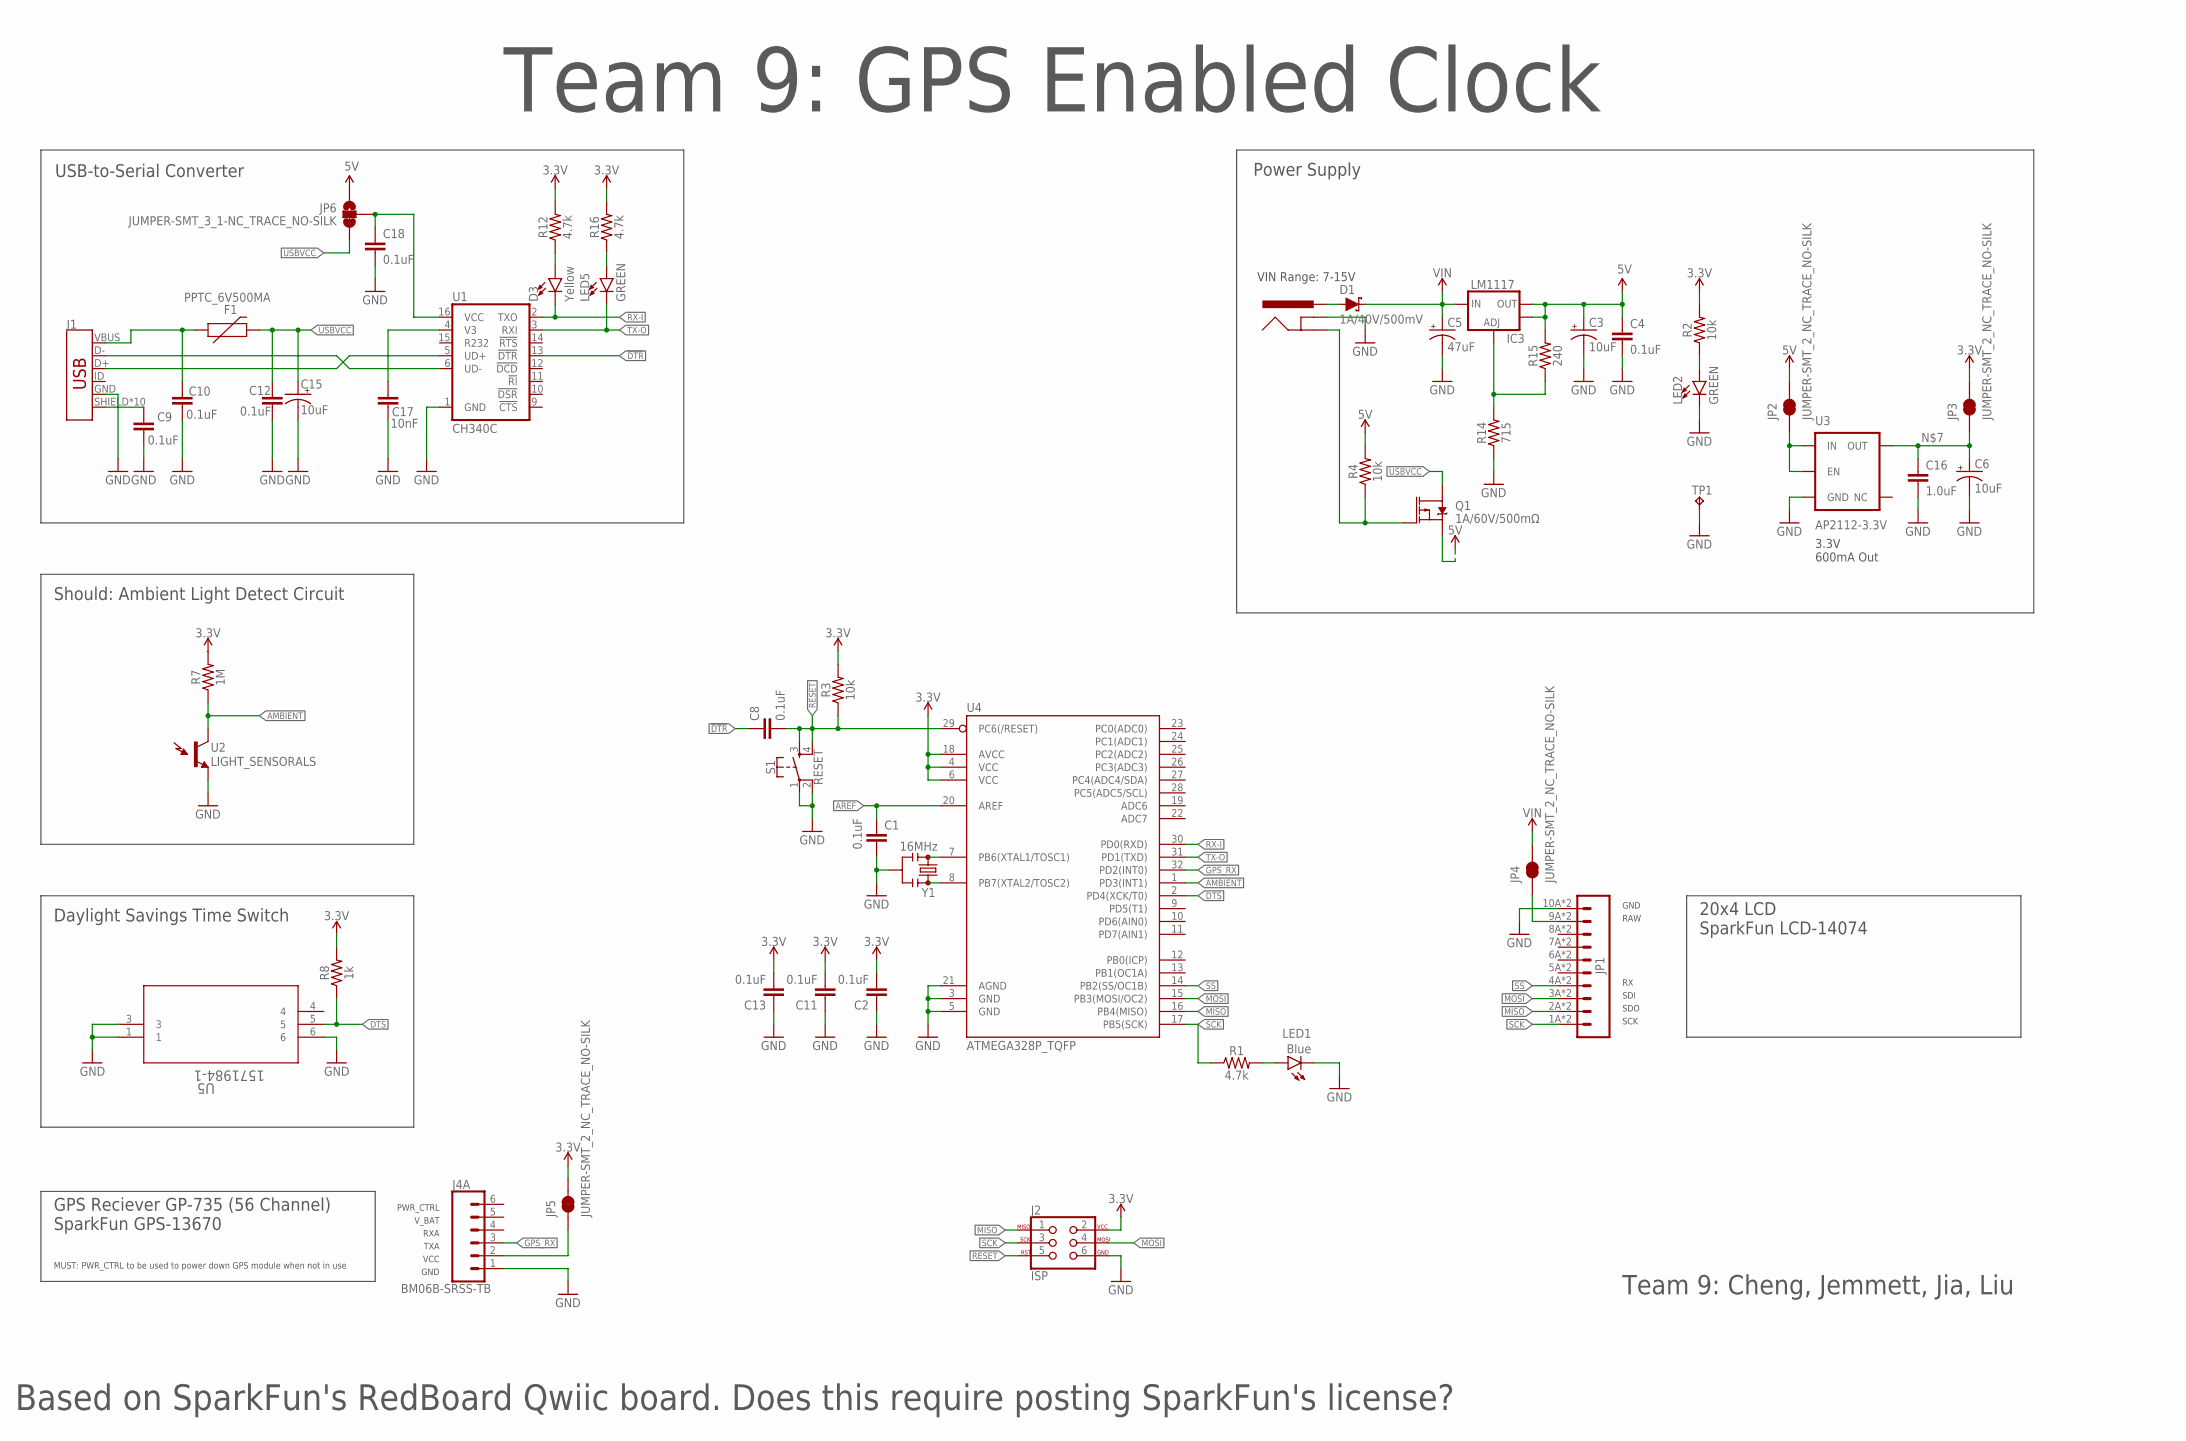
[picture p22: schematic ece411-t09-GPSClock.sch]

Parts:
C1, C2, C4, C8, C9, C10, C11, C12, C13, C18: 0.1uF; 0603
C3, C6, C15: 10uF; EIA3216
C5: 47uF; PANASONIC_D
C16: 1.0uF; 0603-CAP
C17: 10nF; 0603-CAP
D1: 1A/40V/500mV; SMA-DIODE
D3: Yellow; LED-1206-HIDDENSILK
F1: PPTC_6V500MA; 0805
IC3: LM1117; SOT223-ALT1
J1: AMP FCI 10103594-0001LF; USB-MICROB-PTH-MILL
J2: ISP; 2X3_SMT_POSTS
J3: POWER_JACKSUPER_BOMB_DIGITY; POWER_JACK_SMD_OVERPASTE_SUPER_BOMB_DIGITY
J4: BM06B-SRSS-TB; JST-6-SMD-HORI-1.0MM
JP1: M10SMD_COMBO; 1X10_SMD_COMBINED
JP2, JP3, JP4, JP5: JUMPER-SMT_2_NC_TRACE_NO-SILK; SMT-JUMPER_2_NC_TRACE_NO-SILK
JP6: JUMPER-SMT_3_1-NC_TRACE_NO-SILK; SMT-JUMPER_3_1-NC_TRACE_NO-SILK
LED1: Blue; LED-1206-HIDDENSILK
LED2, LED5: GREEN; LED-1206-HIDDENSILK
Q1: 1A/60V/500mΩ; SOT23-3
R1, R12, R16: 4.7k; 0603
R2, R3, R4: 10k; 0603
R7: 1M; 0603
R8: 1k; 0603
R14: 715; 0603
R15: 240; 0603
S1: RESET; TACTILE_SWITCH_SMD_5.2MM
TP1: TP-063
U1: CH340C; SO016
U2: LIGHT_SENSORALS; ALS-PT19
U3: AP2112-3.3V; SOT23-5
U4: ATMEGA328P_TQFP; TQFP32-08
U5: 1571984-1; SWITCH_1571984-1
Y1: 16MHz; RESONATOR-SMD-3.2X1.3

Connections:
3.3V: C2.2, C11.2, C13.2, J2.2, JP3.2, JP5.2, R2.2, R3.2, R7.2, R8.2, R12.2, R16.2, U4.4 (VCC), U4.6 (VCC), U4.18 (AVCC)
5V: C3.+, C4.1, IC3.2 (OUT), IC3.4 (OUT), JP2.2, JP6.1, Q1.2 (S), R4.2, R15.2
!DTR: C8.1, U1.13 (!DTR)
AMBIENT: R7.1, U2.C (C1), U4.1 (PD3(INT1))
AREF: C1.1, U4.20 (AREF)
DTS: R8.1, U4.2 (PD4(XCK/T0)), U5.5
GND: C1.2, C2.1, C3.-, C4.2, C5.-, C6.-, C9.2, C10.2, C11.1, C12.2, C13.1, C15.-, C16.2, C17.2, C18.2, J1.GND, J2.6, J3.GND (GNDBREAK), J4.1, JP1.10A (10), JP1.10B (10), LED1.C, LED2.C, R14.1, S1.1, S1.2, TP1.1, U1.1 (GND), U2.E (E1), U3.2 (GND), U4.3 (GND), U4.5 (GND), U4.21 (AGND), U5.1, U5.3, U5.6, Y1.2
GPS_RX: J4.3, U4.32 (PD2(INT0))
INSERT: J3.P$4 (GND), Q1.1 (G), R4.1
MISO: J2.1, JP1.2A (2), JP1.2B (2), U4.16 (PB4(MISO))
MOSI: J2.4, JP1.3A (3), JP1.3B (3), U4.15 (PB3(MOSI/OC2))
unnamed: LED1.A, R1.2
unnamed: LED2.A, R2.1
unnamed: U4.7 (PB6(XTAL1/TOSC1)), Y1.1
unnamed: U4.8 (PB7(XTAL2/TOSC2)), Y1.3
unnamed: LED5.A, R16.1
unnamed: C17.1, U1.4 (V3)
unnamed: C6.+, C16.1, JP3.1, U3.5 (OUT)
unnamed: JP2.1, U3.1 (IN), U3.3 (EN)
unnamed: D3.A, R12.1
unnamed: JP1.9A (9), JP1.9B (9), JP4.1
unnamed: J4.2, JP5.1
unnamed: C18.1, JP6.2, U1.16 (VCC)
unnamed: J1.D-, U1.6 (UD-)
unnamed: J1.D+, U1.5 (UD+)
unnamed: IC3.1 (ADJ), R14.2, R15.1
PWRIN: D1.A, J3.VIN0 (PWR)
RESET: C8.2, J2.5, R3.1, S1.3, S1.4, U4.29 (PC6(/RESET))
RX-I: D3.C, U1.2 (TXO), U4.30 (PD0(RXD))
SCK: J2.3, JP1.1A (1), JP1.1B (1), R1.1, U4.17 (PB5(SCK))
SHLD: C9.1, J1.SHIELD, J1.SHIELD2 (SHIELD), J1.SHIELD3 (SHIELD), J1.SHIELD4 (SHIELD), J1.SHIELD5 (SHIELD), J1.SHIELD6 (SHIELD), J1.SHIELD7 (SHIELD), J1.SHIELD8 (SHIELD), J1.SHIELD9 (SHIELD), J1.SHIELD10 (SHIELD)
SS: JP1.4A (4), JP1.4B (4), U4.14 (PB2(SS/OC1B))
TX-O: LED5.C, U1.3 (RXI), U4.31 (PD1(TXD))
USBVCC: C12.1, C15.+, F1.2, JP6.3, Q1.3 (D)
VIN: C5.+, D1.C, IC3.3 (IN), JP4.2
VUSB: C10.1, F1.1, J1.VBUS

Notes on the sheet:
Power Supply
USB-to-Serial Converter
VIN Range: 7-15V
3.3V 600mA Out
Should: Ambient Light Detect Circuit
Team 9: GPS Enabled Clock
Based on SparkFun's RedBoard Qwiic board. Does this require posting SparkFun's license?
GPS Reciever GP-735 (56 Channel) SparkFun GPS-13670
20x4 LCD SparkFun LCD-14074
SDI
SDO
SCK
RAW
GND
VCC
TXA
RXA
V_BAT
PWR_CTRL
MUST: PWR_CTRL to be used to power down GPS module when not in use
Team 9: Cheng, Jemmett, Jia, Liu
Daylight Savings Time Switch

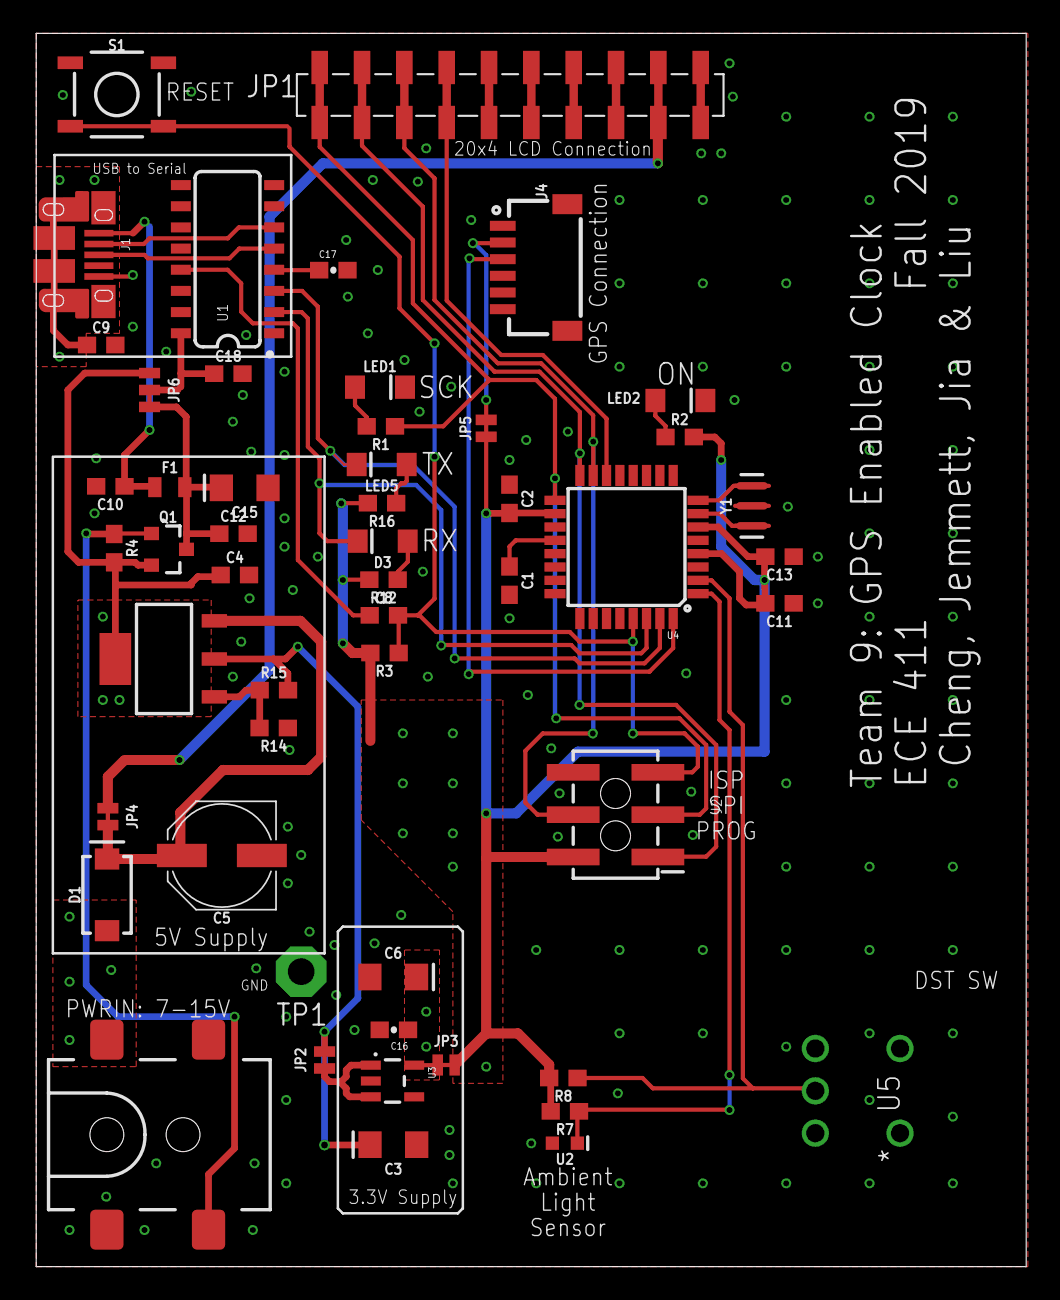
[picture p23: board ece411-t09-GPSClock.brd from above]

Board: 2 copper layers, 59.4 x 74.0 mm, 52 parts (0 on the bottom side), 36 nets.

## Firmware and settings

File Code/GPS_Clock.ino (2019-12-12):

/*
  GPS Enabled Clock
  ECE 411
  Fall 2019
  Cheng, Jia, Jemmett, & Liu

  Based on Sparkfun project by Nathan Seidle. (See discription below)
*/


/*
  OpenLCD is an LCD with Serial/I2C/SPI interfaces.
  By: Nathan Seidle
  SparkFun Electronics
  Date: April 19th, 2015
  License: This code is public domain but you buy me a beer if you use this and we meet someday (Beerware license).
  This is example code that shows how to send data over SPI to the display.
*/





#include <SPI.h> // For writing to LCD & serial console
#include <SerLCD.h>  //https://www.arduinolibraries.info/libraries/spark-fun-ser-lcd-arduino-library
#include <SoftwareSerial.h> // For reading from GPS

// initialize the library
SerLCD lcd;

SoftwareSerial GPSSerial(2, 3); // RX, TX. Only RX used for recieving GPS data

// make some custom characters to display signal strength:
byte Sig1[8] = {
  0b00000,
  0b00000,
  0b00000,
  0b00000,
  0b00000,
  0b00000,
  0b00000,
  0b10000
};
byte Sig2[8] = {
  0b00000,
  0b00000,
  0b00000,
  0b00000,
  0b00000,
  0b00000,
  0b01000,
  0b11000
};
byte Sig3[8] = {
  0b00000,
  0b00000,
  0b00000,
  0b00000,
  0b00000,
  0b00100,
  0b01100,
  0b11100
};
byte Sig4[8] = {
  0b00000,
  0b00000,
  0b00000,
  0b00000,
  0b00010,
  0b00110,
  0b01110,
  0b11110
};
byte Sig5[8] = {
  0b00000,
  0b00000,
  0b00000,
  0b00001,
  0b00011,
  0b00111,
  0b01111,
  0b11111
};
byte Sig6[8] = {
  0b00000,
  0b00000,
  0b00001,
  0b00011,
  0b00111,
  0b01111,
  0b11111,
  0b11111
};
byte Sig7[8] = {
  0b00000,
  0b00001,
  0b00011,
  0b00111,
  0b01111,
  0b11111,
  0b11111,
  0b11111
};
byte Sig8[8] = {
  0b00001,
  0b00011,
  0b00111,
  0b01111,
  0b11111,
  0b11111,
  0b11111,
  0b11111
};


int csPin = 10; // Declare RedBoard's Pin 10 connected to LCD's cs pin
int GPSPin = 2; // Declare RedBoard's Pin 2 connected to GPS
int AmbientSensor = 3; // Declare RedBoard's Pin 3 connected to Ambient Light Sensor
int DSTSwitch = 4; // Declare RedBoard's Pin 4 connected to DTS switch

int cycles = 0;
//int local_hour_offset = -8; //PST is -8 hours from UTC


float Long = 0;
float Lat = 0;
char buffer[20]; //"Tuesday" and stuff
char today[20];
char time[7]; //145205 = 2:52:05
char Latitude[4];
char Longitude[5];
char LatDir[2];
char LongDir[2];
char Elevation[16];
float EAS = 0; // Elevation above Sealevel in meters
char date[7]; //123114 = Dec 31, 2014
char sats[3]; //08 = 8 satellites in view
byte SIV = 0; // converted # of satalites in view
int TimeZone = 0; // converted from Longitude and LongDir
char tempString[50]; //Needs to be large enough to hold the entire string with up to 5 digits
bool dark = true;
bool DST = false;
char Location[14];
bool Morning;
bool Init = true;
char dateDisplay[20];
char LocDisplay[20];
char EASDisplay[20];
bool SATtime = false;
bool SATLong = false;
bool SATLat = false;

void setup()
{

  // Open serial communications and wait for port to open:
  Serial.begin(9600); // For writing to serial monitor
  GPSSerial.begin(9600); // For reading GPS
  while (!GPSSerial) {
    ; // wait for serial port to connect. Needed for Native USB only
  }

  pinMode(csPin, OUTPUT); // Declare csPin (pin 10) as output to LCD
  pinMode(GPSPin, INPUT); // Declare GPSPin (pin 2) as input from GPS
  pinMode(AmbientSensor, INPUT); // Declare AmbientSensor (pin 3) as input from GPS
  pinMode(DSTSwitch, INPUT); // Declare GDTSSwitch (pin 24) as input from GPS

  SPI.begin();

  lcd.begin(SPI, csPin, SPISettings(100000, MSBFIRST, SPI_MODE0));

  //Clear the display
  lcd.clear();

  //Print a message to the LCD.
  lcd.setCursor(0, 0); // set the cursor to column 2, line 0
  lcd.print(" GPS Enabled Clock  ");
  lcd.setCursor(0, 1); // set the cursor to column 2, line 0
  lcd.print("ECE 411     PSU 2019");
  lcd.setCursor(0, 2); // set the cursor to column 2, line 0
  lcd.print("   Cheng, Jemmett,  ");
  lcd.setCursor(0, 3); // set the cursor to column 2, line 0
  lcd.print("     Jia, & Liu     ");

  delay(10000);

  //Clear the display & set backlight
  lcd.clear();
  lcd.setFastBacklight(0, 250, 0);

  // Declare the custom Signal strength characters
  lcd.createChar(0, Sig1);
  lcd.createChar(1, Sig2);
  lcd.createChar(2, Sig3);
  lcd.createChar(3, Sig4);
  lcd.createChar(4, Sig5);
  lcd.createChar(5, Sig6);
  lcd.createChar(6, Sig7);
  lcd.createChar(7, Sig8);


  // Wait for GPS reciver to warm up
  for (byte x = 0 ; x < 300 ; x++)
  {
    checkGPS();
    //Serial.println(SATtime);
    if (!checkGPS && !SATtime)
    {
      lcd.setCursor(0, 0);
      lcd.print("                          ");
      lcd.setCursor(0, 1);
      lcd.print("     Please wait          ");
      lcd.setCursor(0, 2);
      lcd.print("   Calibrating GPS      ");
      sprintf(buffer, "     %03d           ", (300 - x));
      lcd.print(buffer);
      delay(1000);
    }
    else
    {
      Serial.println("break");
      break;
    }
    //Serial.println(x);
  }


}

void loop()
{
  // Check Ambient lighting and adjust brightness only on intial lighting change
  // Light probably won't be strobing so no need for interupt
  if ((dark == false) && (digitalRead(AmbientSensor)))
  {
    lcd.setFastBacklight(0, 80, 0); // Light came on. Turn off backlight
    Serial.println("DARK");
    dark = true;
  }
  if ((dark == true) && (!digitalRead(AmbientSensor)))
  {
    lcd.setFastBacklight(0, 250, 0); // Light went out. Turn on backlight
    Serial.println("LIGHT");
    dark = false;
  }


  if (checkGPS() == true) //Checks for new serial data
  {
    //Serial.println("Available");
    //Crack strings into usable numbers
    int year;
    byte day, month;
    crackDate(&day, &month, &year);


    int hour;
    byte minute, second;
    crackTime(&hour, &minute, &second);

    SIV = 0;
    crackSatellites(&SIV);

    TimeZone = 0;

    //Convert time to local time using daylight savings if necessary
    convertToLocal(&day, &month, &year, &hour);

    // Display time on row 1
    lcd.setCursor(0, 0); // set the cursor to column 0, line 0



    // Display if it's morning or evening
    if (Morning)
    {
      sprintf(buffer, "%02d:%02d:%02d AM    ", hour, minute, second);
    }
    else
    {
      sprintf(buffer, "%02d:%02d:%02d PM    ", hour, minute, second);
    }
    lcd.print(buffer);



    // Display if user has indicated DST
    lcd.setCursor(15, 0); // set the cursor to column 19, line 0
    if (DST)
    {
      lcd.print("DST");
    }
    else
    {
      lcd.print("    ");
    }



    // Display Signal Strength based on the number of satellites in view
    lcd.setCursor(19, 0); // set the cursor to column 19, line 0
    if (SIV > 7)
    {
      lcd.writeChar(7);
    }
    else
    {
      lcd.writeChar(SIV - 1);
    }


    // Display Day and Date on row 2
    if (Init  ||  (int)minute == 0)
    {
      byte DoW = day_of_week(year, month, day);
      if (DoW == 0) sprintf(dateDisplay, "Sunday    %02d/%02d/%02d", month, day, year);
      if (DoW == 1) sprintf(dateDisplay, "Monday    %02d/%02d/%02d", month, day, year);
      if (DoW == 2) sprintf(dateDisplay, "Tuesday   %02d/%02d/%02d", month, day, year);
      if (DoW == 3) sprintf(dateDisplay, "Wednesday %02d/%02d/%02d", month, day, year);
      if (DoW == 4) sprintf(dateDisplay, "Thursday  %02d/%02d/%02d", month, day, year);
      if (DoW == 5) sprintf(dateDisplay, "Friday    %02d/%02d/%02d", month, day, year);
      if (DoW == 6) sprintf(dateDisplay, "Saturday  %02d/%02d/%02d", month, day, year);
    }
    lcd.setCursor(0, 1); // set the cursor to column 0, line 1
    lcd.print(dateDisplay);




    if(SATLat & SATLong)
    {
    sprintf(LocDisplay, "Loc: %02d.%02d%s %03d.%02d%s        ", (int)Lat, (int)((Lat - ((int)Lat)) * 100 + .01), LatDir, (int)Long, (int)((Long - ((int)Long)) * 100 + .01), LongDir);
    sprintf(EASDisplay, "Elevation: %dm     ", (int) EAS);
    }
    else
    {
      sprintf(LocDisplay, "                    ");
      sprintf(EASDisplay, "                    ");
    }
    lcd.setCursor(0, 2);
    lcd.print(LocDisplay);
    //Serial.println(LocDisplay);
    lcd.setCursor(0, 3);
    lcd.print(EASDisplay);
    //Serial.println(EAS);
    //Serial.println(EASDisplay);






    delay(150);
  }
  else if (!checkGPS && SATtime)
  {
    int hour;
    byte minute, second;
    crackTime(&hour, &minute, &second);

    //Display no signal message
    lcd.setCursor(0, 0);
    lcd.print("                          ");
    lcd.setCursor(0, 1);
    sprintf(buffer, "    %02d:%02d:%02d UTC     ", hour, minute, second);
    lcd.print(buffer);
    lcd.setCursor(0, 2);
    lcd.print("                          ");
    lcd.setCursor(0, 3);
    lcd.print("                          ");
    delay(250);
  }
  else if (!SATtime)
  {
    //Serial.println(time);
    //Display no signal message
    lcd.setCursor(0, 0);
    lcd.print("                          ");
    lcd.setCursor(0, 1);
    lcd.print("   No GPS Signal      ");
    lcd.setCursor(0, 2);
    lcd.print("                          ");
    lcd.setCursor(0, 3);
    lcd.print("                          ");
    delay(250);
  }


  Init = false;

}





//Looks at the incoming serial stream and tries to find time, date and sats in view
boolean checkGPS()
{
  unsigned long start = millis();
  SATtime = false;
  SATLong = false;


  //Give up after a second of polling
  while (millis() - start < 1500)
  {
    // Determine if GPS information is recievable
    if (GPSSerial.available())
    {
      //Serial.println("Available");
      if (GPSSerial.read() == '$') // Read characters until we get to the start of a sentence
      {
        //Serial.println("start");
        // Read sentence type
        char sentenceType[6];
        for (byte x = 0 ; x < 6 ; x++)
        {
          while (GPSSerial.available() == 0)
          {
            delay(1); //Wait
          }
          sentenceType[x] = GPSSerial.read();
        }
        sentenceType[5] = '\0';

        if (sentenceType[3] == 'G' && sentenceType[4] == 'A') // Continue if format is GPGGA ----------------------------------------------
        {
          //Serial.println("GPGGA");
          //We are now listening to the GPGGA sentence for time and number of sats
          //$Message ID,UTC Time,Latitude,N/S,Longitude,E/W,Pos Indicator,SIV,HDOP,MSL Altitude,Geoidal Seperation,Units,Age of Diff Corr,CheckSum,<CR><LF>
          //6d,9d,10d,1d,11d,1d,1d,2d,4d,4d,1d,?,?,3d,?
          //$GPGGA,145205.00,3902.08127,N,10415.90019,W,2,08,2.68,1611.4,M,-21.3,M,,0000*5C

          //Serial.println(time);
          //Grab time
          for (byte x = 0 ; x < 6 ; x++)
          {
            while (GPSSerial.available() == 0) delay(1); //Wait
            time[x] = GPSSerial.read(); //Get time characters


            //Error check for a time that is too short
            if (time[x] == ',')
            {
              Serial.println("No time found");
              return (false);
            }
          }
          time[6] = '\0';
          SATtime = true;
          //Serial.println(time);








          //Wait for 1 comma to go by
          for (byte commaCounter = 1 ; commaCounter > 0 ; )
          {
            while (GPSSerial.available() == 0) delay(1); //Wait
            char incoming = GPSSerial.read(); //Get time characters
            if (incoming == ',') commaCounter--;
          }


          //Grab Latitude
          for (byte x = 0 ; x < 11 ; x++)
          {
            while (GPSSerial.available() == 0) delay(1); //Wait
            if (x < 4)
            {
              Latitude[x] = GPSSerial.read(); //Get sats in view characters
              //Latitude[x] = ',';
              //Error check for a Latitude that is too short
              if (Latitude[x] == ',')
              {
                Serial.println("No Latitude found");
              }
            }
          }
          Latitude[4] = '\0';
          //Serial.println(Latitude);


          //Wait for 1 comma to go by
          for (byte commaCounter = 1 ; commaCounter > 0 ; )
          {
            while (GPSSerial.available() == 0) delay(1); //Wait
            char incoming = GPSSerial.read(); //Get time characters
            if (incoming == ',') commaCounter--;
          }

          //Grab Latitude Direction, N or S
          for (byte x = 0 ; x < 1 ; x++)
          {
            while (GPSSerial.available() == 0) delay(1); //Wait
            LatDir[x] = GPSSerial.read(); //Get sats in view characters
          }
          LatDir[1] = '\0';
          //Serial.println(LatDir);


          //Wait for 1 comma to go by
          for (byte commaCounter = 1 ; commaCounter > 0 ; )
          {
            while (GPSSerial.available() == 0) delay(1); //Wait
            char incoming = GPSSerial.read(); //Get time characters
            if (incoming == ',') commaCounter--;
          }

          //Grab Longitude
          for (byte x = 0 ; x < 11 ; x++)
          {
            while (GPSSerial.available() == 0) delay(1); //Wait
            if (x < 5)
            {
              Longitude[x] = GPSSerial.read(); //Get sats in view characters

              //Error check for a Longitude that is too short
              if (Longitude[x] == ',')
              {
                //Serial.println("No Longitude found");
                return (false);
              }
            }
          }
          Longitude[5] = '\0';
          //Serial.println(Longitude);

          //Wait for 1 comma to go by
          for (byte commaCounter = 1 ; commaCounter > 0 ; )
          {
            while (GPSSerial.available() == 0) delay(1); //Wait
            char incoming = GPSSerial.read(); //Get time characters
            if (incoming == ',') commaCounter--;
          }



          //Grab Longitude Direction, E or W of UTC
          for (byte x = 0 ; x < 1 ; x++)
          {
            while (GPSSerial.available() == 0) delay(1); //Wait
            LongDir[x] = GPSSerial.read(); //Get sats in view characters
          }
          LongDir[1] = '\0';
          //Serial.println(LongDir);

          SATLong = true;

          //Wait for 2 commas to go by
          for (byte commaCounter = 2 ; commaCounter > 0 ; )
          {
            while (GPSSerial.available() == 0) delay(1); //Wait
            char incoming = GPSSerial.read(); //Get time characters
            if (incoming == ',') commaCounter--;
          }




          //Grab sats in view
          for (byte x = 0 ; x < 2 ; x++)
          {
            while (GPSSerial.available() == 0) delay(1); //Wait
            sats[x] = GPSSerial.read(); //Get sats in view characters
          }
          sats[2] = '\0';
          //Serial.println(sats);

          //Wait for 2 commas to go by
          for (byte commaCounter = 2 ; commaCounter > 0 ; )
          {
            while (GPSSerial.available() == 0) delay(1); //Wait
            char incoming = GPSSerial.read(); //Get time characters
            if (incoming == ',') commaCounter--;
          }

          //Grab Elevation
          for (byte x = 0 ; x < 16 ; x++)
          {
            while (GPSSerial.available() == 0) delay(1); //Wait
            Elevation[x] = GPSSerial.read(); //Get sats in view characters
            if (Elevation[x] == ',')
            {
              Elevation[x] = '\0';
              break;
            }
          }

          int count = 0;
          for (byte x = 0 ; x < 16 ; x++)
          {
            if (Elevation[x] == '\0')
            {
              break;
            }
            count++;

          }
          //Serial.println(Elevation);
          //Serial.println(count);
          EAS = 0;
          for (int x = count - 3; x > -1; x--)
          {
            EAS += (Elevation[count - (x + 3)] - '0') * pow(10, x);

          }

          EAS += (Elevation[count - 1] - '0') * pow(10, (-1));
          //Serial.println(Elevation[count-1]);
          //Serial.println(EAS);



          //Once we have GPGGA, we should already have GPRMC so return
          return (true);
        }
        else if (sentenceType[3] == 'M' && sentenceType[4] == 'C') // Continue if format is GPRMC ----------------------------------------------
        {
          //We are now listening to GPRMC for the date
          //Message ID,UTC Time,Status,Latitude,N/S,Longitude,E/W,Speed,Course,Date,Magnetic Variation, Mode, Checksum,<CR><LF>
          //6d,9d,1d,10d,1d,11d,1d,6d,6d,?,1d,3d,?
          //$GPRMC,145205.00,A,3902.08127,N,10415.90019,W,0.772,,010115,,,D*6A

          //Wait for 8 commas to go by
          for (byte commaCounter = 8 ; commaCounter > 0 ; )
          {
            while (GPSSerial.available() == 0) delay(1); //Wait
            char incoming = GPSSerial.read(); //Get time characters
            if (incoming == ',') commaCounter--;
          }

          //Grab date
          for (byte x = 0 ; x < 6 ; x++)
          {
            while (GPSSerial.available() == 0) delay(1); //Wait
            date[x] = GPSSerial.read(); //Get date characters

            //Error check for a date too short
            if (date[x] == ',')
            {
              //Serial.println("No date found");
              return (false);
            }
          }
          date[6] = '\0';
          //Serial.println(date);
        }

      }
    }
  }

  Serial.println("No valid GPS serial data");
  return (false);
}




//Given date and hours, convert to local time using DST
void convertToLocal(byte* day, byte* month, int* year, int* hours)
{
  // Determine if the user has declared DST
  if (digitalRead(DSTSwitch))
  {
    DST = false;
  }
  else
  {
    DST = true;
    *hours = *hours + 1; //In DST add an extra hour
  }

  

  //Convert Longitude
  Lat = (Latitude[1] - '0') * 10;
  Lat += (Latitude[2] - '0');
  Lat += (Latitude[3] - '0') * 0.1;
  Lat += (Latitude[4] - '0') * 0.01;
  //Serial.println(Lat);

  // Determine time zone based on Longitude

  Long = (Longitude[0] - '0') * 100;
  Long += (Longitude[1] - '0') * 10;
  Long += (Longitude[2] - '0');
  Long += (Longitude[3] - '0') * 0.1;
  Long += (Longitude[4] - '0') * 0.01;
  //Serial.println(Long);

  //Serial.println(*hours);

  //Determine Time zone based on longitude
  //https://www.quora.com/How-do-I-calculate-time-using-longitudes-and-latitudes
  //"Every 15 degrees of longitude equals 1 hour. So, if you are standing at 0 degrees longitude
  //and you move or travel 15 degrees east or west, you'll notice a difference of 1 hour.
  //This 1 hour difference is negative or positive, can be determined by the direction in
  //which you have traveled i.e westwards or eastwards of the Meridian longitude."

  if (LongDir[0] == 'W')
  {
    TimeZone = -1 * Long / 15;
  }
  else
  {
    TimeZone = Long / 15;
  }
  //Serial.println(TimeZone);


  //Serial.println(*hours);
  //Serial.println(abs(TimeZone));
  //Convert UTC hours to local current time based on time zone

  if (*hours < abs(TimeZone))
  {
    //Go back a day in time
    *day = *day - 1;

    if (*day == 0)
    {
      //Determine if this changes the date
      *month = *month - 1;

      if (*month == 1) *day = 31;
      if (*month == 2) *day = 28;
      if (*month == 3) *day = 31;
      if (*month == 4) *day = 30;
      if (*month == 5) *day = 31;
      if (*month == 6) *day = 30;
      if (*month == 7) *day = 31;
      if (*month == 8) *day = 31;
      if (*month == 9) *day = 30;
      if (*month == 10) *day = 31;
      if (*month == 11) *day = 30;
      if (*month == 0)
      {
        *year = *year - 1;
        *month = 12;
        *day = 31;
      }
    }

    //Serial.println(*hours);
    *hours = *hours + 24; //Add 24 hours before subtracting local offset
    //Serial.println(*hours);
  }
  *hours = *hours + TimeZone;
  //Serial.println(*hours);
  if (*hours > 11)
  {
    if (*hours > 12)
    {
      *hours = *hours - 12; //Get rid of military time
    }
    Morning = false;
  }
  else
  {
    Morning = true;
  }
  //Serial.println(*hours);
}

//Given the date string return day, month, year
void crackDate(byte* day, byte* month, int* year)
{
  for (byte x = 0 ; x < 3 ; x++)
  {
    byte temp = (date[ (x * 2) ] - '0') * 10;
    temp += (date[ (x * 2) + 1 ] - '0');

    if (x == 0) *day = temp;
    if (x == 1) *month = temp;
    if (x == 2)
    {
      *year = temp;
      *year += 2000;
    }
  }
}

//Given the time string return hours, minutes, seconds
void crackTime(int* hours, byte* minutes, byte* seconds)
{

  for (byte x = 0 ; x < 3 ; x++)
  {
    byte temp = (time[ (x * 2) ] - '0') * 10;
    temp += (time[ (x * 2) + 1 ] - '0');

    if (x == 0) *hours = temp;
    if (x == 1) *minutes = temp;
    if (x == 2) *seconds = temp;

  }


}



//Given the sats string return satellites in view
void crackSatellites(byte* SIV)
{
  //Serial.println(sats);
  *SIV = (sats[0] - '0') * 10;
  *SIV += (sats[1] - '0');
}
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

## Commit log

2019-11-05 Updated schematic with correct port for GPS Rx
    [GPSClock.sch]
2019-11-07 updated GPS connection, auto routing for starting point
    [GPSClock.brd, GPSClock.csv]
2019-11-07 updated GPS connector
    [GPSClock.sch]
2019-11-18 Completed List from Eagle BOM
    [Parts List.xlsx]
2019-11-18 Updated resonator source and added status column
    [Parts List.xlsx]
2019-11-18 Completed OSH Park's DRC
    [GPSClock.brd, GPSClock.csv, GPSClock.sch]
2019-11-18 Fixed board size
    Fixed board size and power connector location to allow for LCD connection
    [GPSClock.brd]
2019-11-19 Added text to BRD.
    [GPSClock.brd]
2019-11-19 Corrected name for OSH Park
    [ece411-t09-GPSClock.brd, ece411-t09-GPSClock.sch]
2019-11-19 Stitched the N$7 (3.3V) plane
    [ece411-t09-GPSClock.brd]
2019-11-20 Added "RESET" to tplace layer
    [ece411-t09-GPSClock.brd]
2019-11-20 added "ISP SPI PROG" to tplace layer
    [ece411-t09-GPSClock.brd]
2019-12-12 Fixed opening for LCD backlight
    [FrontScaled_1p014.STL]

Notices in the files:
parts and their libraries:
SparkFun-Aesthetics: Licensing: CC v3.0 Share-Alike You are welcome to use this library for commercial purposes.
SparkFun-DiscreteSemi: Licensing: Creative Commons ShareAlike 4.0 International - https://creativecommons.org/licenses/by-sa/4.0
